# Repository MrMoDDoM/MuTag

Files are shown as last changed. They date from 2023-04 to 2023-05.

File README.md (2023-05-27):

# MuTag v2.1
Repository for PCB and source file of the MuHack NFC Tag keychain.

This is a custom printed circuit board featuring an ATTiny44a microcontroller and an ST25 NFC ISO15 tag. 

From the MCU is it possible to access the NFC tag using I2C, to modify the tag's configuration and read/write data.

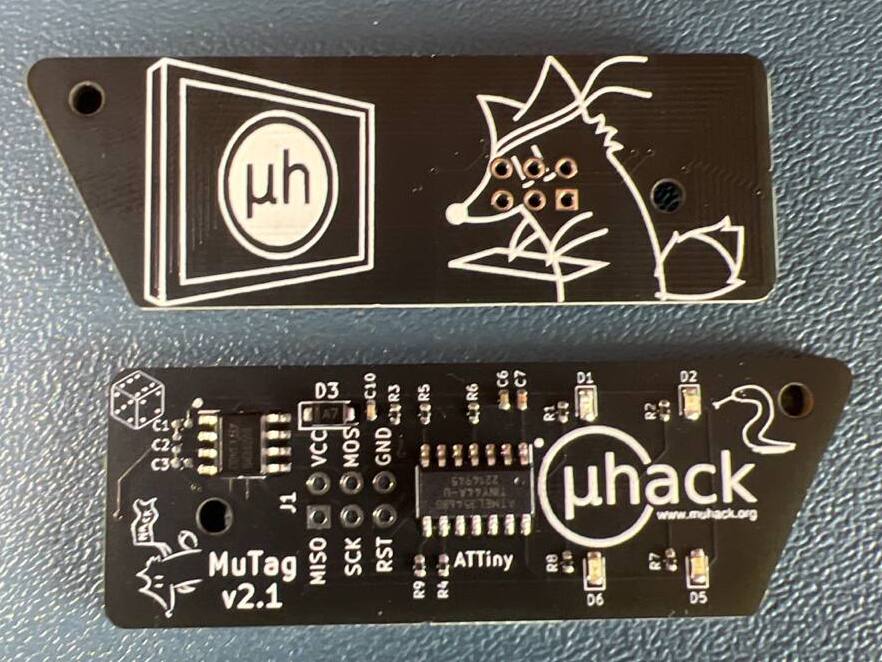
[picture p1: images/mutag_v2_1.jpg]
MuTag


## Features
- ATTiny44a MCU
- ST25 NFC ISO15 tag with 4Kbit memory
- Energy harvesting
- Fast transfer memory, 256bytes of _Mailbox_
- 4 LEDs of different colors
- I2C and UART (TBD) interfaces 
- Small form factor: only 20x60mm

# Getting Started

In the Hardware folder you can find the PCB design files and the schematics. 

```
#define YELLOW_LED 0
#define GREEN_LED 1
#define BLUE_LED 2
#define RED_LED 3
```

The LEDs are connected to:
- Yellow led on pin 0 (Port PA0)
- Green led on pin 1 (Port PA1)
- Blue led on pin 2 (Port PA2)
- Red led on pin 3 (Port PA3)

The NFC tag is connected to the ATTiny's I2C bus:
- SDA on pin 6 (Port PA6)
- SCL on pin 4 (Port PA4)

The NFC GPO is also connected to the ATTiny's INT0 interrupt port (Port PB2).

## Activating Energy Harvesting Mode with the ST25 Android App

By default, the ST25 NFC tag is set to "on demand" energy harvesting mode.
To activate energy harvesting mode on the ST25 NFC IC, you will need to use the ST25 Android app (future implementation of the software will automatically activate this through the I2C communication).

Follow these steps:

1. Download the ST25 Android app from the Google Play Store (https://play.google.com/store/apps/details?id=com.st.st25nfc)

2. Scan the tag with the ST25 Android app and from the left menu go to "Register Management"

3. Re-scan the tag to update the tag's configuration. You will see a register called ``EH_MODE``. By default, this register is set to ``0x01``, which means that energy harvesting mode is set "on demand". To enable energy harvesting mode, change the value of this register to ``0x00``

4. While maintaining the tag in the field, tap the "Save" button to write the new configuration to the tag (the default password is all zeros, just tap "OK" to continue)

## Programming the ATTiny44a MCU

Generally speaking, the ATTiny44a MCU must be programmed using an external ISP programmer. In this case, we will use an Arduino Uno as an ISP programmer (you can use any other Arduino board that can be used as an ISP). 

1. Flash the ```ArduinoISP``` sketch (found in the File -> Example menu) to an Arduino (or any other Arduino board that can be used as an ISP)

2. Add the following line to "Additional Boards Manager URLs" in the Arduino IDE preferences:

```http://drazzy.com/package_drazzy.com_index.json```

3. Install the ```ATTinyCore``` by __Spence Konde__ board definition (found in the Tool -> Board -> Board Manager menu) and select the following settings:

| Setting | Value |
|---------|-------|
| Board | ATTiny24/44/84 (noBootloader) |
| Chip | ATTiny44(a) (*Note: for v2.0 select 24*)|
| Clock | 1 MHz internal |
| BOD | Disabled |
| LTO | Enabled |
| EEPROM | EEPROM retained |
| millis()/micros() | Enabled |
| Programmer | Arduino as ISP |

4. Connect the MuTag to the Arduino as follows:

| MuTag | Arduino |
|-------|---------|
| VDD   | 5V      |
| GND   | GND     |
| SCK   | 13      |
| MISO  | 12      |
| MOSI  | 11      |
| RST   | 10      |

~~*NOTE: The MuTag through hole ports are of 1.27mm diameter, enough to fit a common jumper wire. So with a little bit of patience you can push the pin rigth into the hole without soldering.*~~ 

*The holes dimension was changed to a standard 2.54mm in the v2.1*

5. Take another jump wire and connect it the ```RESET``` pin of the Arduino and leave the other end unconnected

6. Now the tricky part: to program the MuTag we need to send the Arduino in "reset mode" for a short period of time. To do this, we need to connect the ```RESET``` pin of the Arduino to ground (i.e. by touching the USB ground shield with the unconnected end the ```RESET``` wire) rigth before we press the "Upload" button in the Arduino IDE. Wait about 2/3 seconds and then release the RESET wire. You should see the Arduino IDE uploading the sketch to the MuTag.

*NOTE: Depending on your Arduino IDE version, you might need to use the "Upload using Programmer" option in the Sketch menu instead of the "Upload" button.*

## Accessing the NFC Tag with the I2C Interface
The internal memory of the ST25 NFC tag can be accessed through the I2C bus as a standard EEPROM memory. The I2C address of the tag is ```0x53```.

The "Hello_MuHack.ino" sketch is a simple example of how to read and write data to the tag.

## TODOS:
- [ ] Add a 3D model of the PCB
- [ ] Find a good bootloader to enable UART programming 
- [x] Evaluate the possibility of removing the diodes
- [x] Evaluate to move and make bigger pads for programming
- [x] Evaluate to change the MCU to an ATTiny44/84 to have more memory
- [x] Evaluate to remove the ```RESET``` pad

## Notes on the Bootloader
The bootloader is a small piece of code that is stored in the MCU's memory and that allows to program via UART. This is very useful because it avoid the need of an external SPI programmer.

The [Optiboot version compiled by Spence Konde](https://github.com/SpenceKonde/ATTinyCore/blob/v2.0.0-devThis-is-the-head-submit-PRs-against-this/avr/extras/ATtiny_x4.md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) uses the pins ```AIN0``` and ```AIN1```, currently connected to the LEDs. This leaves us with two options:
- Remove the LEDs and use the pins for programming via UART
- Recompiling the bootloader to use different pins

Since this project is intended to be used as a keychain, which means that is to be programmed only once, I decided to not invest time in the bootloader and leave the LEDs as they are.

## License
Copyright (c) 2023 MrMoDDoM

This project is licensed under the GNU AFFERO GENERAL PUBLIC License - see the [LICENSE.md](LICENSE.md) file for details

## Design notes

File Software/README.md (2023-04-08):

# Software
This directory contains sketches and libraries for the MuTag project.

## Board Definition

```
#define YELLOW_LED 0
#define GREEN_LED 1
#define BLUE_LED 2
#define RED_LED 3

#define INT_PIN 8 // INT0

#define TAG_I2C_ADDR 83
```

## Rainbow
This sketch is used to test the LEDs on the MuTag board. It will cycle through all LEDs present on the board.

## Hello MuHack
This sketch is used to test the I2C communication with the NFC tag on the MuTag board. It will check if the 224th bytes of the tag's memory is equal to ```0x01```. If it is, it will write "Hello MuHack!", otherwise it will erease said memory.

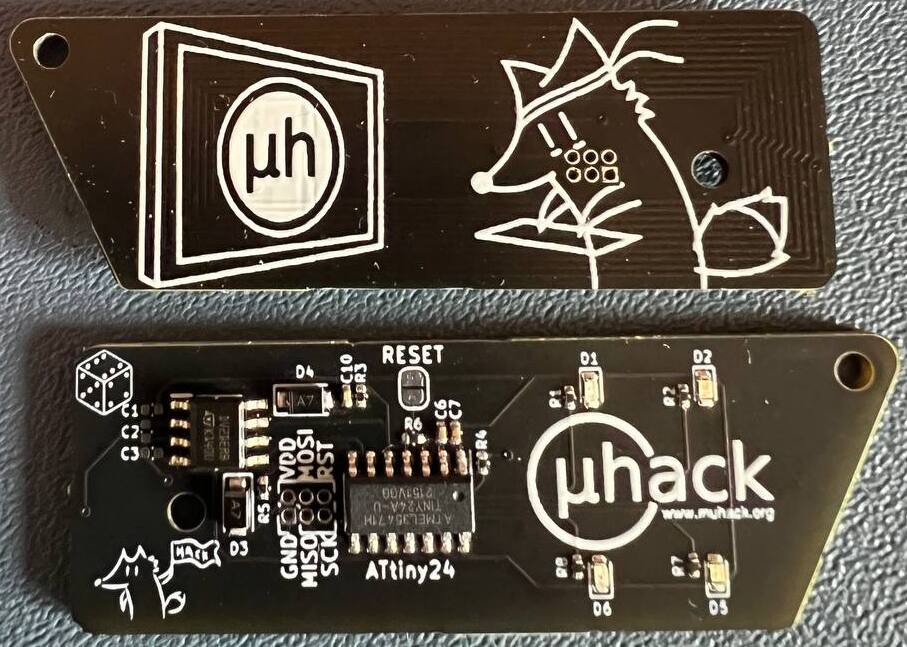
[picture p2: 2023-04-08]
images/mutag_v2.jpg

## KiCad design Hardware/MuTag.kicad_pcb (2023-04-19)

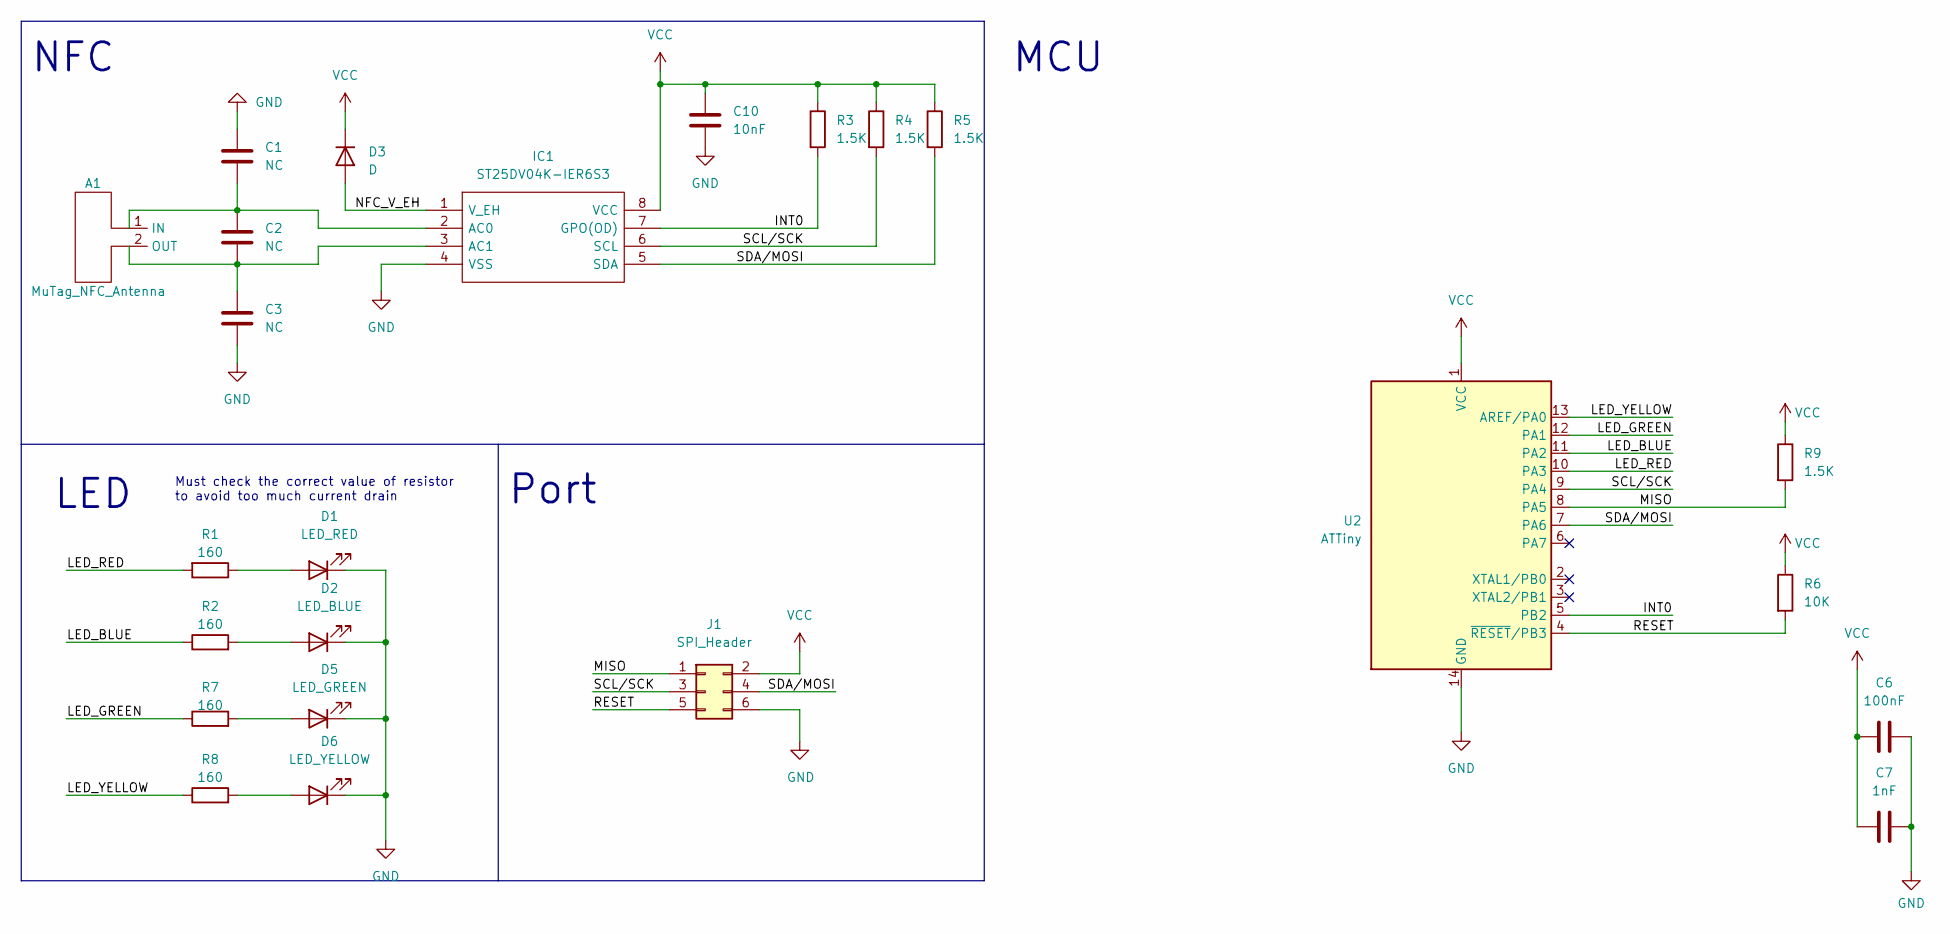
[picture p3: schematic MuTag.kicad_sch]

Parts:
A1: MuTag_NFC_Antenna; mutag_new_antenna
C1, C2, C3: NC; C_0402_1005Metric
C6: 100nF; C_0402_1005Metric
C7: 1nF; C_0402_1005Metric
C10: 10nF; C_0402_1005Metric
D1: LED_RED; LED_0603_1608Metric
D2: LED_BLUE; LED_0603_1608Metric
D3: D; D_SOD-123F
D5: LED_GREEN; LED_0603_1608Metric
D6: LED_YELLOW; LED_0603_1608Metric
IC1: ST25DV04K-IER6S3; SOIC127P600X175-8N; Manufacturer_Part_Number ST25DV04K-IER6S3; Mouser Part Number 511-ST25DV04K-IER6S3
J1: SPI_Header; PinHeader_2x03_P2.54mm_Vertical
R1, R2, R7, R8: 160; R_0402_1005Metric
R3, R4, R5, R9: 1.5K; R_0402_1005Metric
R6: 10K; R_0402_1005Metric
U2: ATTiny; SOIC-14_3.9x8.7mm_P1.27mm

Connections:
/INT0: IC1.7 (GPO(OD)), R3.2, U2.5 (PB2)
/LED_BLUE: R2.1, U2.11 (PA2)
/LED_GREEN: R7.1, U2.12 (PA1)
/LED_RED: R1.2, U2.10 (PA3)
/LED_YELLOW: R8.1, U2.13 (AREF/PA0)
/MISO: J1.1, R9.2, U2.8 (PA5)
/NFC_V_EH: D3.2 (A), IC1.1 (V_EH)
/RESET: J1.5, R6.2, U2.4 (~RESET/PB3)
/SCL/SCK: IC1.6 (SCL), J1.3, R4.2, U2.9 (PA4)
/SDA/MOSI: IC1.5 (SDA), J1.4, R5.2, U2.7 (PA6)
GND: C1.1, C3.2, C6.2, C7.2, C10.2, D1.1 (K), D2.1 (K), D5.1 (K), D6.1 (K), IC1.4 (VSS), J1.6, U2.14 (GND)
unnamed: A1.1 (IN), C1.2, C2.1, IC1.2 (AC0)
unnamed: A1.2 (OUT), C2.2, C3.1, IC1.3 (AC1)
unnamed: D1.2 (A), R1.1
unnamed: D2.2 (A), R2.2
unnamed: D5.2 (A), R7.2
unnamed: D6.2 (A), R8.2
VCC: C6.1, C7.1, C10.1, D3.1 (K), IC1.8 (VCC), J1.2, R3.1, R4.1, R5.1, R6.1, R9.1, U2.1 (VCC)

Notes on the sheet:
NFC
LED
Port
Must check the correct value of resistor to avoid too much current drain
MCU

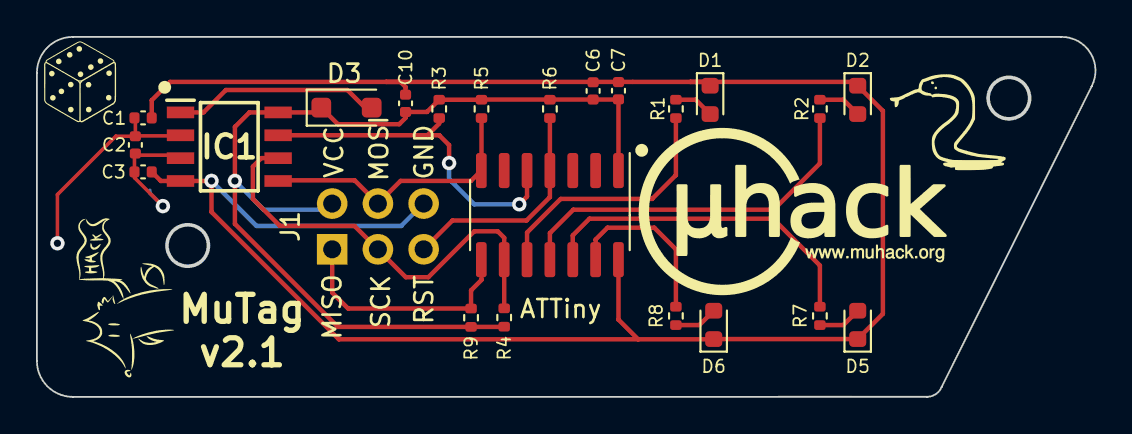
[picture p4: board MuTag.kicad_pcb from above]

Board: 2 copper layers, 58.8 x 20.0 mm, 24 parts (1 on the bottom side), 18 nets.

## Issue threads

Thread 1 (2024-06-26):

Correct pin connections for USBasp

GKnirps, 2024-06-26:
Hi,
I got a MuTag at the Chaos Communication Camp last year and I finally found some time to play around with it.

On [this page](https://muhack.org/events/CCC23-landing-page/), you say I can also use a [USBasp](https://www.fischl.de/usbasp/) for programming the tag. This is convenient because I already have one of those.

However, I'm a bit at a loss of which pins to connect. For the Arduino solution, the readme files lists the correct connections but I cannot find anything about the USBasp.

Can someone help me out here?

MrMoDDoM, 2024-06-27:
Hi!
The USBasp should have a set of MISO/MOSI as well clock and reset pins.

Depending on your version, you should be able to access the 6Pin header on your board ( https://www.datasheetcafe.com/usbasp-pinout-avr-programmer/ )

Then simply match the data line name ;)

| USBasp | MuTag |
|--------|----------|
|    VCC    |    VCC      |
|     GND   |    GND   |
|  SCK | SCK |
| RST | RST |
| MISO | MISO |
| MOSI | MOSI |

MrMoDDoM, 2024-07-09:
Yes, you are correct, the VCC is the 5v power line, and RST is the indeed reset :)
The only two line you should double check are the VCC and GND (ground) ones, as they can damage the Tag if connected wrongly.. you can mess up how much you want the other line, they can not do any harm ;)

As before, simply match the line name between the Tag and the USBasp, using the 10 pin header is fine.

GKnirps, 2024-09-06:
Thanks again. I have not been able to do anything with the tag yet because I don't have the appropriate cables actually connect it to the USBAsp (to be fair, I don't even know what I should use, nothing really sticks in there), but the pin layout is now pretty clear, so I'll close this ticket.

MrMoDDoM, 2024-09-09:
Hi, to clarify a little bit more, you can also use an Arduino to program the Tag, the USBAsp is compatible as well but maybe a little too complicated to use..
If you have difficulties, I can assist you with step-by-step guidance: the procedure is the same as using an Arduino as ISP Programmer ( https://docs.arduino.cc/built-in-examples/arduino-isp/ArduinoISP/ ), you can also find countless tutorial and video on how to program a target MCU (in our case the MuTag) with this procedure https://www.youtube.com/watch?v=TtC6crf_EP4

GKnirps, 2024-09-11:
Thanks, I will get back to you when I run into problems!

Closed 2024-09-06.

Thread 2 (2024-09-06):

ST25 NFC Tap responds with "Tag unknown"

GKnirps, 2024-09-06:
Hi,
sorry to bother again. In the readme file it says I should use the ST25 NFC Tap app to enable energy harvesting mode or else I would not be able to run programs on the tag. I'm not _that_ interested to run programs, but it looks like this is the only way to change the data that is transferred via NFC.

However, when I start the ST25 NFC Tap app and put the MuTag in front of the sensor, the app says "Tag unknown" and nothing else. How do I fix this?

Also: There already is data on the tag, it is this URL `https://muhack.org/events/CCC23-landing-page/`. Does that mean that the energy harvesting mode has already been activated at some point?

MrMoDDoM, 2024-09-09:
Hi,
That's kinda odd, does the same behavior appear with other phone/reader or with other generic NFC app (like this one https://play.google.com/store/apps/details?id=com.wakdev.wdnfc)? Try at least to read/write some new content to check if the memory of the NFC tag is not corrupted..

The Energy Harvesting mode is mandatory to power the MCU with only the NFC field, but it is **not necessary** to program the MCU nor to read/write NFC Tag.

Before the CCC23 I manually wrote on every tag an URL to some landing page, but I did not activate the Energy Harvesting mode as it require some non-automateble steps that as single person working on this project I didn't have time to do ;)

GKnirps, 2024-09-11:
Hi,
thanks for the reply, and sorry for my rather sluggish responses (I currently have a lot of things going on).

I have no google playstore on my phone, so I always have to jump through hoops to get Apps on the phone that don't exist elsewhere, but with the wakedev app you linked to I was able to write some data to the tag. I'm happy that worked, so I can start to actually use the tag (even though I won't have fancy LED stuff).

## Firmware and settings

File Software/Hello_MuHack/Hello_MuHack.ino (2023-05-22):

#include <Wire.h>

#define YELLOW_LED A0
#define GREEN_LED A1
#define BLUE_LED A2
#define RED_LED A3

#define TAG_I2C_ADDR 83
#define POS_TIMES 212
#define HELLO_POS 224

void setup() {
  
  pinMode(YELLOW_LED, OUTPUT);
  pinMode(GREEN_LED, OUTPUT);
  pinMode(BLUE_LED, OUTPUT);
  pinMode(RED_LED, OUTPUT);

  Wire.begin();
  hello_muhack();
  Wire.end();
}

void loop() {
  digitalWrite(RED_LED, LOW);
  digitalWrite(BLUE_LED, HIGH);
  delay(50);
  digitalWrite(BLUE_LED, LOW);
  digitalWrite(GREEN_LED, HIGH);
  delay(50);
  digitalWrite(GREEN_LED, LOW);
  digitalWrite(YELLOW_LED, HIGH);
  delay(50);
  digitalWrite(YELLOW_LED, LOW);
  digitalWrite(RED_LED, HIGH);
  delay(50);
}

/* 
* This function writes "Hello MuHack!" to the EEPROM 
* only if finds that the first byte is 1.
* Otherwise, it ereases that portion of EEPROM
*/
void hello_muhack() {
  char buf[13] = {0};
  if (readEEPROM(TAG_I2C_ADDR, HELLO_POS) == 1){
    strcpy(buf,"Hello MuHack!");
  } 

  for(int i = 0; i < 13; i++){
    writeEEPROM(TAG_I2C_ADDR, HELLO_POS+i, buf[i]);
  }

}

void writeEEPROM(int deviceaddress, unsigned int eeaddress, byte data ) {
  Wire.beginTransmission(deviceaddress);
  Wire.write((int)(eeaddress >> 8));   // MSB
  Wire.write((int)(eeaddress & 0xFF)); // LSB
  Wire.write(data);
  Wire.endTransmission();
 
  delay(5);
}

byte readEEPROM(int deviceaddress, unsigned int eeaddress ) {
  byte rdata = 0xFF;
 
  Wire.beginTransmission(deviceaddress);
  Wire.write((int)(eeaddress >> 8));   // MSB
  Wire.write((int)(eeaddress & 0xFF)); // LSB
  Wire.endTransmission();
 
  Wire.requestFrom(deviceaddress,1);
 
  if (Wire.available()) rdata = Wire.read();
 
  return rdata;
}

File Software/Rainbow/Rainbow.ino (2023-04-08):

#define YELLOW_LED A0
#define GREEN_LED A1
#define BLUE_LED A2
#define RED_LED A3

#define RAIN_DELAY 50

void setup() {
  pinMode(YELLOW_LED, OUTPUT);
  pinMode(GREEN_LED, OUTPUT);
  pinMode(BLUE_LED, OUTPUT);
  pinMode(RED_LED, OUTPUT);
}

void loop() {
  digitalWrite(RED_LED, LOW);
  digitalWrite(BLUE_LED, HIGH);
  delay(RAIN_DELAY);
  digitalWrite(BLUE_LED, LOW);
  digitalWrite(GREEN_LED, HIGH);
  delay(RAIN_DELAY);
  digitalWrite(GREEN_LED, LOW);
  digitalWrite(YELLOW_LED, HIGH);
  delay(RAIN_DELAY);
  digitalWrite(YELLOW_LED, LOW);
  digitalWrite(RED_LED, HIGH);
  delay(RAIN_DELAY);
}

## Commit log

2023-01-23 First commit - hardware only. Modified gitignore
    [MuTag.kicad_pcb, MuTag.kicad_sch]
2023-03-08 First routing of new version - no antenna
    [MuTag.kicad_pcb, MuTag.kicad_sch]
2023-03-09 New finished routing, with bigger antenna and leds - ready for production
    [MuTag.kicad_pcb, MuTag.kicad_sch]
2023-03-25 Ordered Version v2
    [MuTag.kicad_pcb]
2023-04-08 Second version first commit - produced and tested: all working
    [MuTag.kicad_pcb, MuTag.kicad_sch]
2023-04-13 Version v2.1 - Set production and docs with ATTiny44a, removed diode from VCC port, moved components to fit bigger port, led resistors value changed to 160
    [MuTag.kicad_pcb, MuTag.kicad_sch]
2023-04-19 Modified led resistor to 150 - increased distance between components to be hand soldered - modified graphics
    [MuTag.kicad_pcb]
